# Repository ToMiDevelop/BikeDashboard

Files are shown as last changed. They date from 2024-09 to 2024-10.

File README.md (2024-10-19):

# Bike Dashboard

|Prototype|Boot screen|
|-|-|
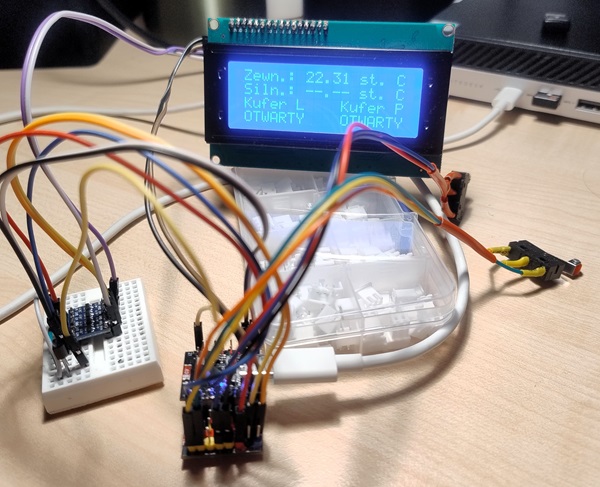
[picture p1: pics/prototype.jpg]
Device prototype
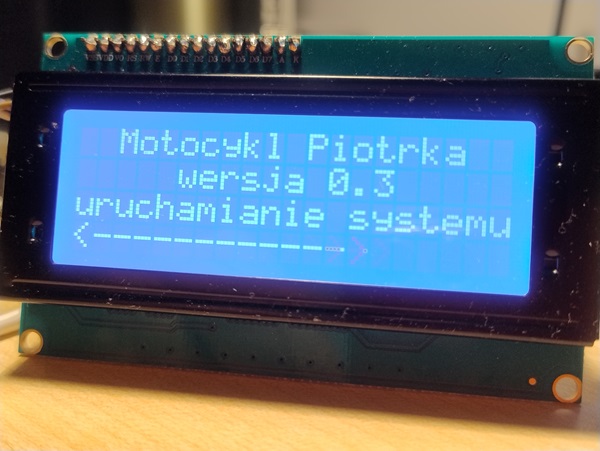
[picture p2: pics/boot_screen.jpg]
||

|Main menu|Left trunk closed, right trunk open|
|-|-|
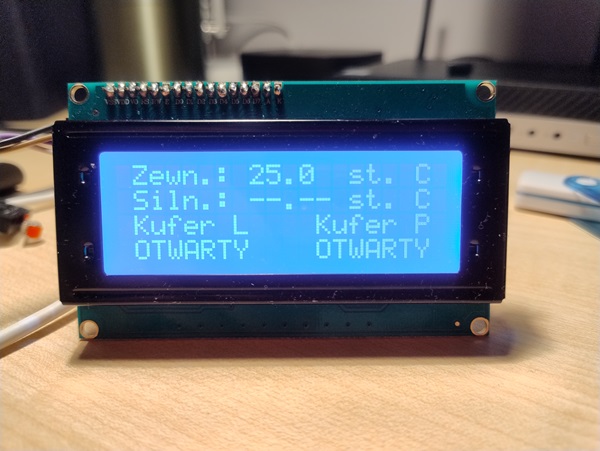
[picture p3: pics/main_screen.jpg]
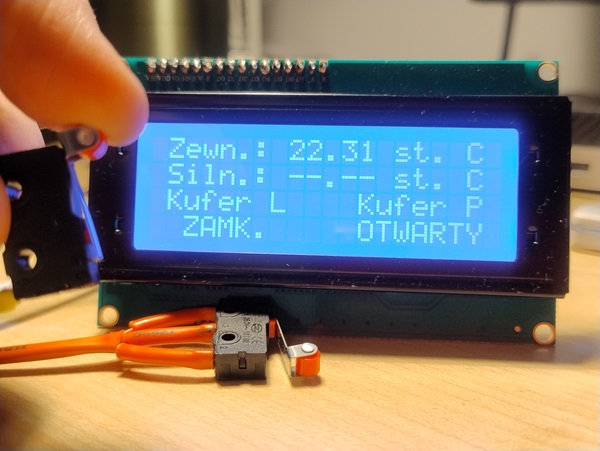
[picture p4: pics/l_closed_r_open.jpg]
||

|Temperature sensors calibration screen|Fully functional main screen|
|-|-|
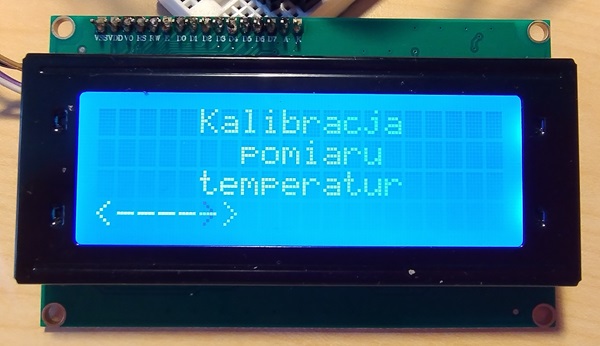
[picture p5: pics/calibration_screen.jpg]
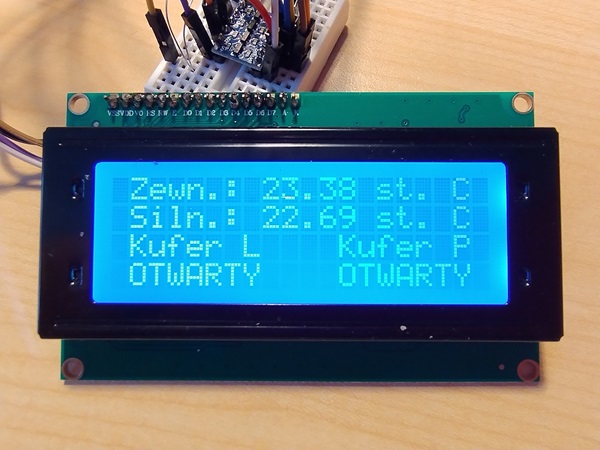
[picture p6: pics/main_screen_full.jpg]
||

|PCB - soldered bottom|PCB - soldered top|
|-|-|
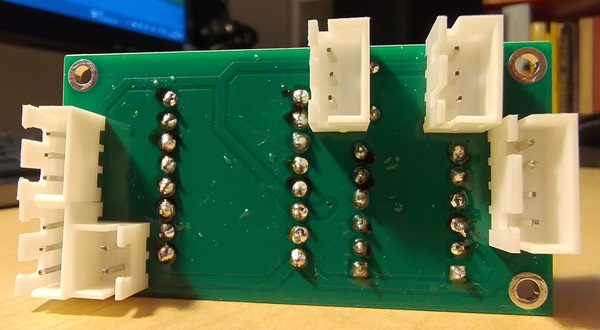
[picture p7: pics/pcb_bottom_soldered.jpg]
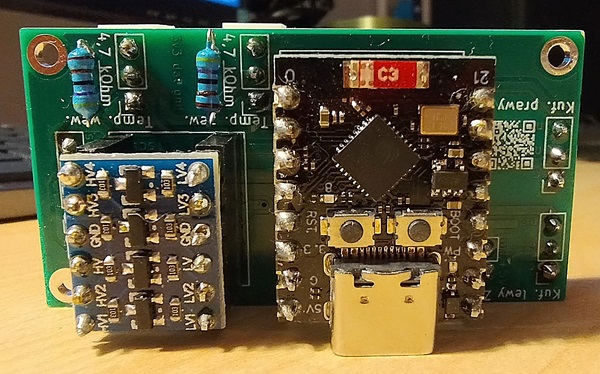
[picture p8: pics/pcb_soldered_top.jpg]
||

## 1. Brief repo description

In this repository you'll find the source code, custom PCB project, connection schematics of a simple digital dashboard tailored for the bike of one of my friends.

## 2. Functionality and key principles

- The device is supposed to show live view of the engine's the outside world's temperature.
- The device shows also the state of 2 trunks - either if they are closed or open.
- The physical design has to enable the temperature sensors to be attached even more than 1 meter away from the microcontroller
- The lcd screen should be attached approx. 1.5 meters away from the microcontroller.
- Main electronics should be mounted in a custom 3d printed case bellow the seat.
- There is a need for a step-down voltage regulator to connect DIY equipment to the battery.

## 3. Used components

- [ESP32-C3 Super-Mini board](https://pl.aliexpress.com/item/1005006096717048.html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)
- [LM2596 step-down voltage regulator](https://botland.com.pl/przetwornice-step-down/4871-przetwornica-step-down-lm2596-32v-35v-3a-z-wyswietlaczem-5904422359560.html)
- [limit switches](https://botland.com.pl/czujniki-krancowe/919-wylacznik-czujnik-krancowy-mini-z-rolka-wk625-5szt-5904422372958.html)
- [DS18B20 temperature sensors](https://botland.com.pl/sondy-wodoodporne/19516-sonda-wodoodporna-z-czujnikiem-temperatury-ds18b20-sent0002-2m-5904422307073.html)
- [4 x 20 character display](https://botland.com.pl/wyswietlacze-alfanumeryczne-i-graficzne/19734-wyswietlacz-lcd-4x20-znakow-niebieski-justpi-5903351243100.html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)
- [I2C converter for character display](https://botland.com.pl/konwertery-pozostale/2352-konwerter-i2c-dla-wyswietlacza-lcd-hd44780-5903351248693.html)
- [bi-directional 4 channel logic level converter](https://botland.com.pl/konwertery-napiec/2259-konwerter-poziomow-logicznych-dwukierunkowy-4-kanalowy-sparkfun-bob-12009-5903351248716.html)
- [4.7 kOhm resistors](https://botland.com.pl/rezystory-przewlekane/20152-rezystor-justpi-tht-cf-weglowy-14w-47k-30szt-5904422329303.html)
- some wires
- some pcb connectors
- PETG 3d printer filament

## 4. Brief source code description

The source code of the scripts running on the board is kept in the **firmware** folder residing in main path of the repository. It contains two subfolders: **lib** and **functions**. Main scripts executed on the board are: **boot.py** and **main.py**. All the folder and files, which need to be transferred to the microcontroller board are visible on the tree bellow.

```
firmware
│
├──── functions
│     ├── display.py
│     ├── temperature.py
│     └── trunk.py
│
├──── lib
│     ├── i2c_lcd.py
│     ├── lcd_api.py
│     └── WIFI_CONFIG.py
│
├── boot.py
└── main.py
```

In the **boot.py** there is some initial configurations and start on boot code. In the **main.py** there is code with the main logic of the application. In **lib** there are libraries used to talk with the display and a wifi configuration file, as the OTA updates are one of the project goals. In **functions** there are modules with classes used to invoke all the individually tailored operations made on display, interactions with the temperature sensor and the limit switches.

## 6. Custom PCB Board

In this project I'm using a custom designed PCB board. All the design files can be found in the **pcb** folder.

```
pcb
│
├──── gerber                            
│     ├── Kokpit Final-B_Cu.gbr        
│     ├── Kokpit Final-B_Mask.gbr       
│     ├── Kokpit Final-B_Paste.gbr  
│     ├── Kokpit Final-B_Silkscreen.gbr
│     ├── Kokpit Final-Edge_Cuts.gbr
│     ├── Kokpit Final-F_Cu.gbr        
│     ├── Kokpit Final-F_Mask.gbr       
│     ├── Kokpit Final-F_Paste.gbr  
│     ├── Kokpit Final-F_Silkscreen.gbr
│     ├── Kokpit Final-job.gbrjob
│     ├── Kokpit Final-NPTH.drl
│     └── Kokpit Final-PTH.drl
│
├──── renders                           
│     ├── Back.png
│     └── Front.png
│
└── BikeDashboard_KiCad.zip

```
In **gerber** folder there are all the generated gerber files. The **BikeDashboard_KiCad.zip** is a export of the whole KiCad project.

|PCB - front render|PCB - back render|
|-|-|
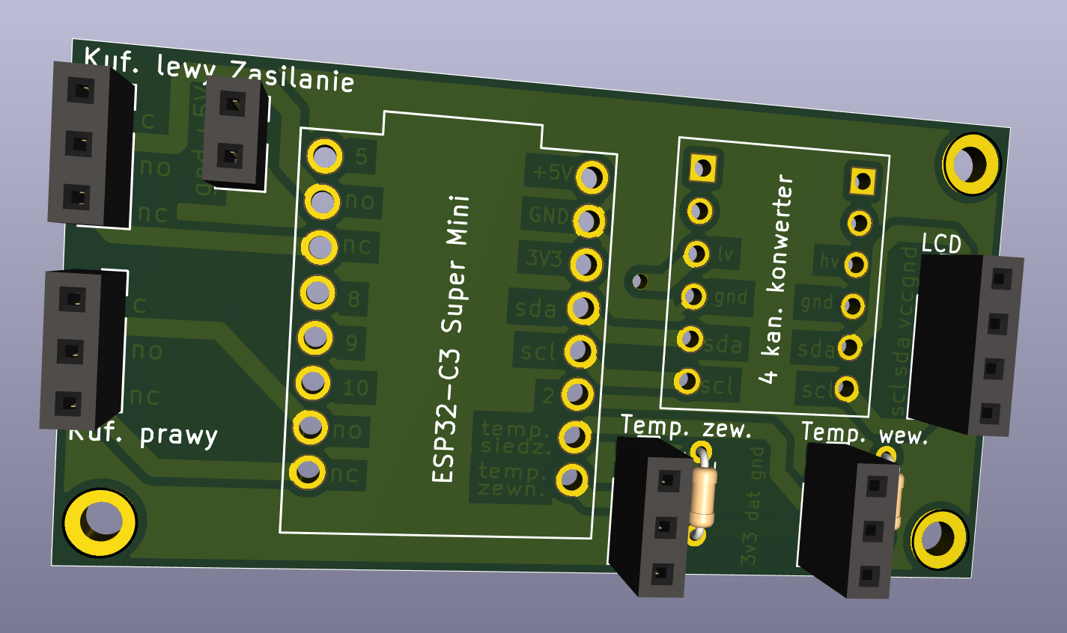
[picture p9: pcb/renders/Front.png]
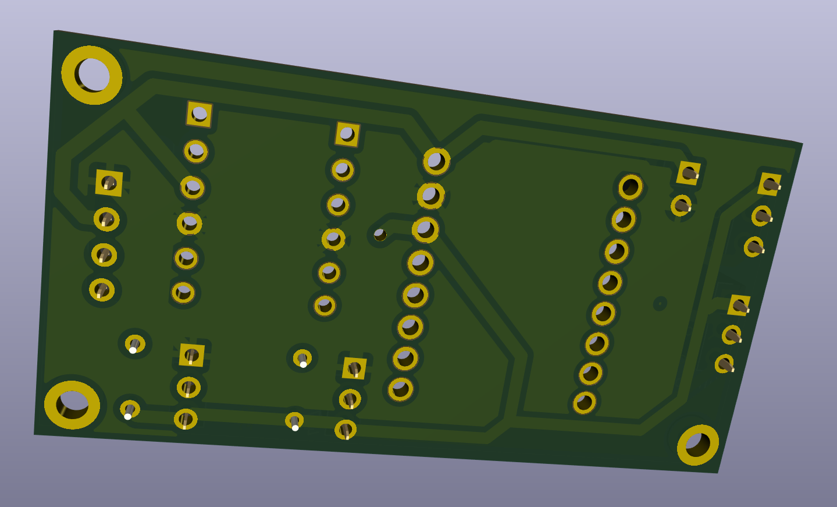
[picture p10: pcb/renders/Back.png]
|||

## 5. Language notice

All of the interface is designed in Polish, you can freely customize it with the translation from **translations.json** file.

## 7. Minor side tools

In the **.sidetools** folder you'll find some small scripts I used to scan the one wire and i2c bus and to test the display.

## 8. Legal notice

I'm the only author of all the work covered in this repository. All the files made publicly available in the repository are licensed under the BikeDasboard project license. The full licence text is available in **LICENSE** file.

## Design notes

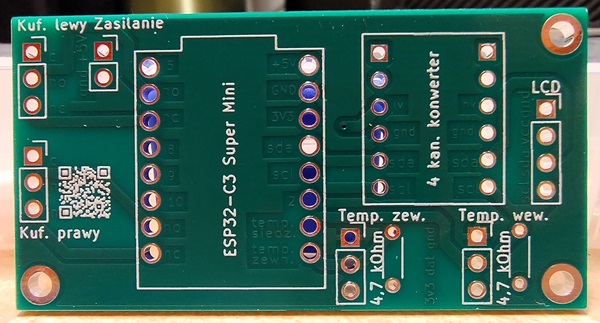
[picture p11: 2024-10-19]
pics/custom_pcb.jpg

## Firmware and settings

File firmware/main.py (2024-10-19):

# Main script file of the Bike's chockpit diplay

# Modules importing

from machine import Pin, SoftI2C
from i2c_lcd import I2cLcd
import utime

# Setting udeful names for chosen pin numbers and pin obejcts

led = Pin(8, Pin.OUT)

i2c_display_sda = 4
i2c_display_scl = 3

switch_lef_nc = Pin(7, Pin.IN, Pin.PULL_DOWN)
switch_right_nc = Pin(21, Pin.IN, Pin.PULL_DOWN)

temp_sensor_pin_external = Pin(0, Pin.PULL_UP)
temp_sensor_pin_engine = Pin(1, Pin.PULL_UP)

# Setting up the parameters of the display

i2c_display_adress = 0x27
i2c_display_rows = 4
i2c_display_columns = 20

# Initilizing the I2C connection to the display

i2c_display_connection = SoftI2C(sda = Pin(i2c_display_sda), scl = Pin(i2c_display_scl), freq = 400000)

# Initializing the object representing the lcd screen

display = I2cLcd(i2c = i2c_display_connection, i2c_addr= i2c_display_adress, num_lines = i2c_display_rows, num_columns = i2c_display_columns)

# Initializating of the object representing the temperature sensor

from temperature import Temperature
DSTemp_external = Temperature(temp_sensor_pin_external)
DSTemp_engine = Temperature(temp_sensor_pin_engine)

# Initilization of class responsible to comunicate with the limit switches

from trunk import Trunk
Trunks = Trunk(switch_lef_nc, switch_right_nc)

# Initializing the object responsible to show infomration on the display

from display import Display
Show = Display(DSTemp_external, DSTemp_engine, Trunks, i2c_display_sda, i2c_display_scl)

 # Showing boot screen and main menu frame

Show.EmptyScreen()
Show.BootScreen()
Show.CalibrateScreen()
Show.MainMenu()

# Test of temperature readings, uncomment if desired

#Show.TemperatureOutside(True, -3.17)
#utime.sleep(6)
#Show.TemperatureOutside(True, -23.97)
#utime.sleep(6)
#Show.TemperatureOutside(True, 6.51)
#utime.sleep(6)
#Show.TemperatureOutside(True, 34.28)
#utime.sleep(6)

# Setting start point to count time interval to refresh temp (counted in seconds)

start = utime.time()

# Setting temp refrersh interval length (in seconds)

interval = 60

# Initial temperature display

Show.TemperatureOutside()

# Main app loop continuosly refreshing the temperature and trunks state

while True:
    Show.TrunksState()
    end = utime.time()
    if end - start >= interval:
        # Sprawdzenie i wyświetlenie temperatury
        Show.TemperatureOutside()
        Show.TemperatureEngine()
        start = end

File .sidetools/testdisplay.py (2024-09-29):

# Głóny skrypt kokpitu motorowego

# Iport modułów

from machine import Pin, SoftI2C
from lcd_api import LcdApi
from i2c_lcd import I2cLcd
import utime

# Nadanie nazw funkcjonalnych odpowiednim pinom

led = Pin(8, Pin.OUT)

i2c_display_sda = 5
i2c_display_scl = 6

# Określenie paramtrów wyświetlacza

i2c_display_adress = 0x27
i2c_display_rows = 4
i2c_display_columns = 20

# Określenie parametrów połączenia z wyświetlaczem

i2c_display_connection = SoftI2C(sda = Pin(i2c_display_sda), scl = Pin(i2c_display_scl), freq = 400000)

# Utworzenie obiektu reprezentującego wyświetlacz

display = I2cLcd(i2c = i2c_display_connection, i2c_addr= i2c_display_adress, num_lines = i2c_display_rows, num_columns = i2c_display_columns)

while True:
    display.move_to(0,0)
    display.putstr("Policzmy od 1 do 20!")
    utime.sleep(3)
    display.clear()
    display.move_to(0,0)
    display.putstr("Liczba:")
    for i in range(20):
        counted = str(i+1)
        if i+1 < 10:
            counted = '0' + counted
        display.move_to(0,2)
        display.putstr(counted)
        utime.sleep(1)
    display.clear()

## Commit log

2024-09-29 Added engine temperature menu line. Minor changes.
2024-10-06 Documentation cleaning up.
    [Kokpit Final-B_Cu.gbr, Kokpit Final-B_Mask.gbr, Kokpit Final-B_Paste.gbr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]
2024-10-19 Added code logic for engine temperature sensor.
2024-10-19 Added uOTA
    [uota.cfg]
2024-10-19 Failed OTA update test
    [uota.cfg]
2024-10-19 Minor documentation update, added pictures of soldered pcb board.
